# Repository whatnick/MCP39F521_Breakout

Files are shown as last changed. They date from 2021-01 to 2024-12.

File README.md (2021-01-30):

# MCP39F521 Breakout PCB

This is a basic breakout PCB for the [MCP39F521](https://www.microchip.com/wwwproducts/en/MCP39F521)
ASIC from Microchip. This ASIC has ADC's and an embedded PIC microcontroller to perform high-accuracy
energy measurements. The ASIC can appear in upto 4 i2c addresses based on jumper settings. The breakout
board is usable with this [Arduino Library](https://github.com/upbeatlabs/drwattson/tree/master/Arduino/UpbeatLabs_MCP39F521)

## PCB Design

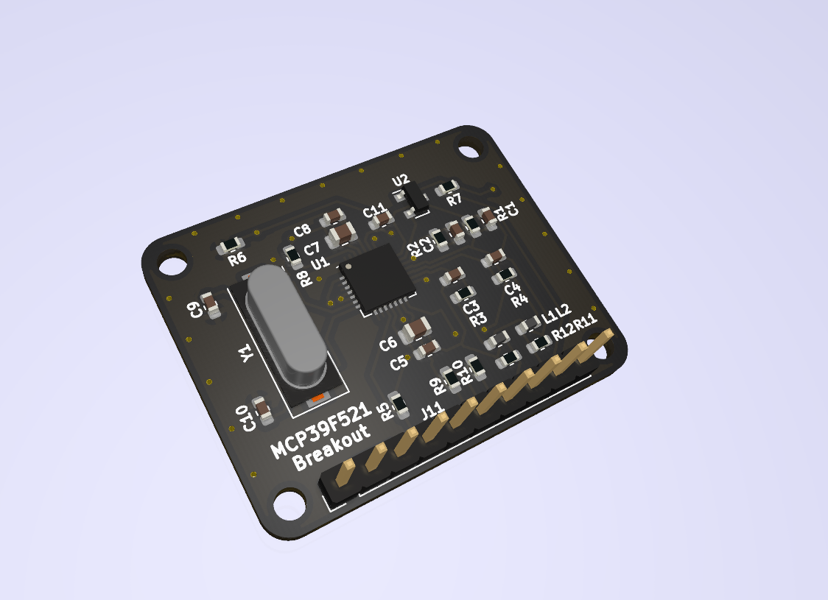
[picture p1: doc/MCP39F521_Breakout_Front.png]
PCB Front


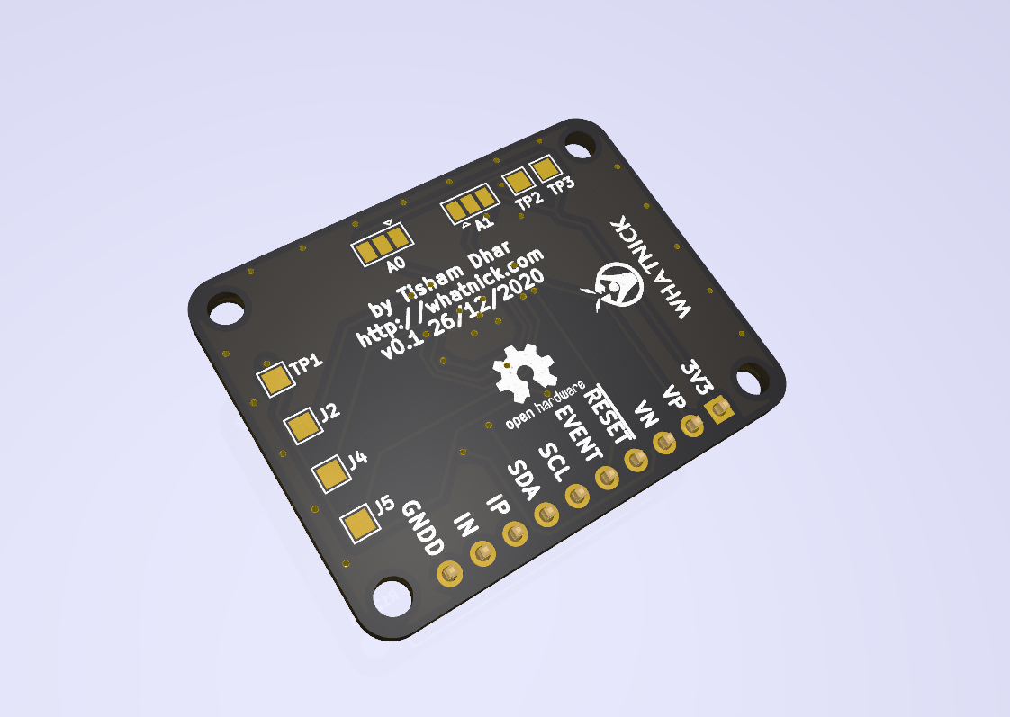
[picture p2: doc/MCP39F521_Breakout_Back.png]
PCB Back


## PCB Availabilty

- [Tindie]()
- [PCBWay]()
- [Aisler]()
- [OSHPark]()

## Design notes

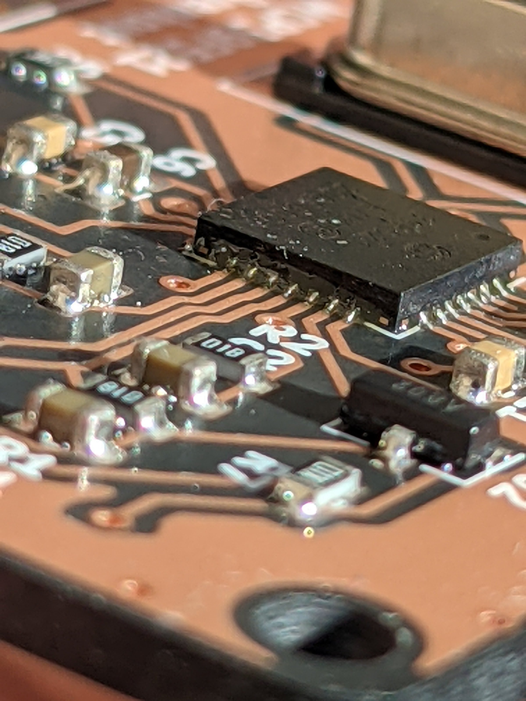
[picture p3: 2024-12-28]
doc/mcp39f521_zoom.jpg

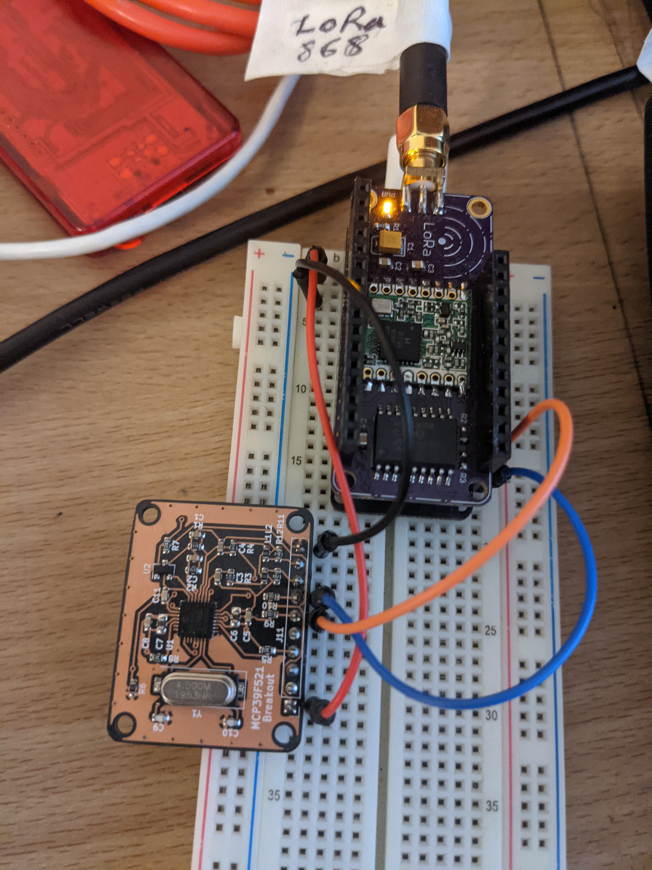
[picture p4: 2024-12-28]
doc/mcp39f521_i2c_connect.jpg

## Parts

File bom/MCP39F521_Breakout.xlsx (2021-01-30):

References | manf# | Value | Footprint | Quantity
C1, C2, C3, C4 | 0603YC333KAT2A | 33nF 50V | C_0603_1608Metric | 4
C5, C8, C11 | C0603C104K4PACTU | 0.1uF 25V | C_0603_1608Metric | 3
C9, C10 | C0603C220K4GACTU | 22pF | C_0603_1608Metric | 2
C6, C7 | CL21A225KAFNNNE | 2.2uF 25V | C_0805_2012Metric | 2
R7 | CR0603-FX-10R0ELF | 10R | R_0603_1608Metric | 1
R1, R2, R3, R4 | CR0603-FX-1501ELF | 1.5k | R_0603_1608Metric | 4
R9, R10 | CR0603-JW-222ELF | 2.2k | R_0603_1608Metric | 2
R5, R8 | CR0603-JW-472ELF | 4.7k | R_0603_1608Metric | 2
R6 | CR0603AJ/-000EAS | 0R | R_0603_1608Metric | 1
R11, R12 | CRL0603-FW-2R40ELF | 2.4R | R_0603_1608Metric | 2
L1, L2 | NFZ2MSD301SZ10L | FB 300ohm | L_0603_1608Metric | 2
U1 | MCP39F521-E/MQ | MCP39F521 | QFN-28-1EP_5x5mm_P0.5mm_EP3.35x3.35mm | 1
U2 | MCP9700T-E/TT | MCP9700AT-ETT | SOT-23 | 1
Y1 | LFXTAL003071Reel | Crystal | Crystal_SMD_HC49-SD | 1

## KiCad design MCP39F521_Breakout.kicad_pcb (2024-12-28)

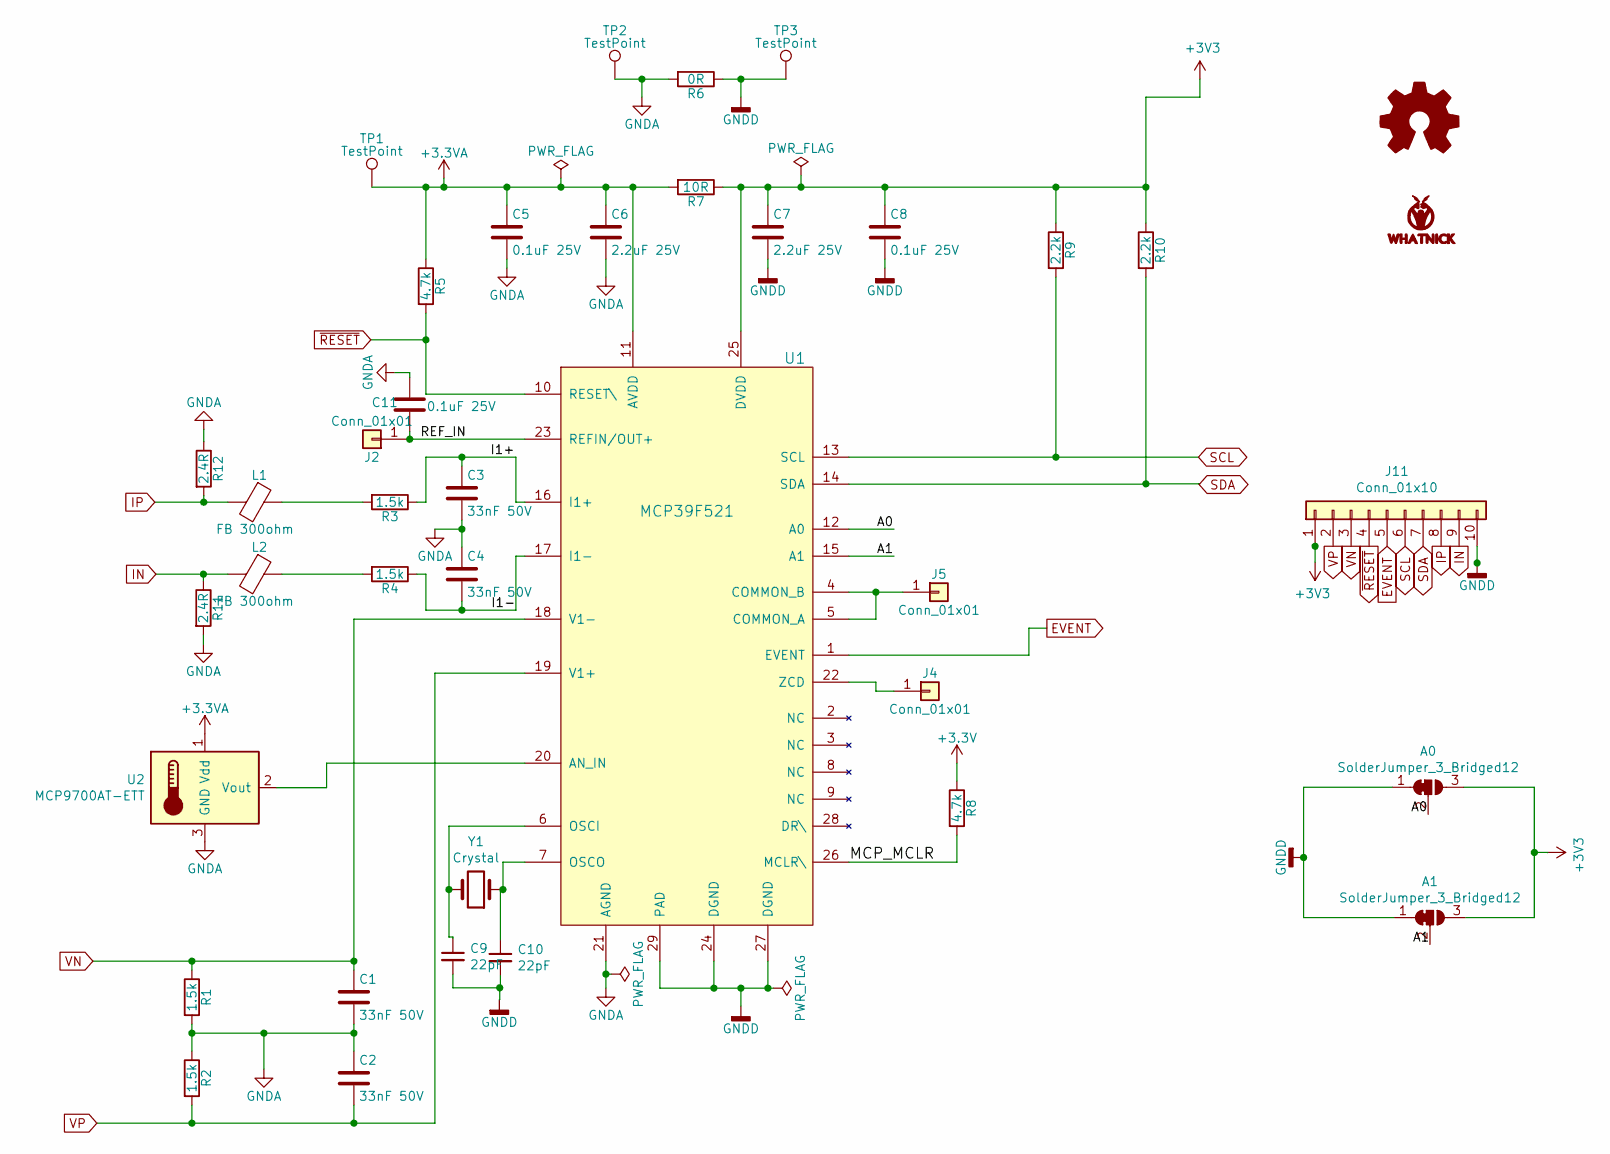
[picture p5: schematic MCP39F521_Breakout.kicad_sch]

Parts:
A0, A1: SolderJumper_3_Bridged12; SolderJumper-3_P1.3mm_Bridged12_Pad1.0x1.5mm
C1, C2, C3, C4: 33nF 50V; C_0603_1608Metric
C5, C8, C11: 0.1uF 25V; C_0603_1608Metric
C6, C7: 2.2uF 25V; C_0805_2012Metric
C9, C10: 22pF; C_0603_1608Metric
J2, J4, J5: Conn_01x01; TestPoint_Pad_1.5x1.5mm
J11: Conn_01x10; PinHeader_1x10_P2.54mm_Vertical
L1, L2: FB 300ohm; L_0603_1608Metric
LOGO1: Logo_Open_Hardware_Small; OSHW-Logo2_7.3x6mm_SilkScreen
LOGO2: LOGO; Whatnick_logo
R1, R2, R3, R4: 1.5k; R_0603_1608Metric
R5, R8: 4.7k; R_0603_1608Metric
R6: 0R; R_0603_1608Metric
R7: 10R; R_0603_1608Metric
R9, R10: 2.2k; R_0603_1608Metric
R11, R12: 2.4R; R_0603_1608Metric
TP1, TP2, TP3: TestPoint; TestPoint_Pad_1.5x1.5mm
U1: MCP39F521; QFN-28-1EP_5x5mm_P0.5mm_EP3.35x3.35mm
U2: MCP9700AT-ETT; SOT-23
Y1: Crystal; Crystal_SMD_HC49-SD

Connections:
+3.3VA: C5.1, C6.1, R5.1, R7.2, TP1.1, U1.11 (AVDD), U2.1 (Vdd)
/A0: A0.2 (C), U1.12 (A0)
/A1: A1.2 (C), U1.15 (A1)
/I1+: C3.1, R3.1, U1.16 (I1+)
/I1-: C4.2, R4.1, U1.17 (I1-)
/MCP_MCLR: R8.2, U1.26 (MCLR\)
/REF_IN: C11.2, J2.1, U1.23 (REFIN/OUT+)
EVENT: J11.5, U1.1 (EVENT)
GNDA: C1.2, C2.1, C3.2, C4.1, C5.2, C6.2, C11.1, R1.2, R2.1, R6.2, R11.2, R12.1, TP2.1, U1.21 (AGND), U2.3 (GND)
GNDD: A0.1 (A), A1.1 (A), C7.2, C8.2, C9.2, C10.2, J11.10, R6.1, TP3.1, U1.24 (DGND), U1.27 (DGND), U1.29 (PAD)
IN: J11.9, L2.2, R11.1
IP: J11.8, L1.2, R12.2
unnamed: C9.1, U1.6 (OSCI), Y1.2
unnamed: C10.1, U1.7 (OSCO), Y1.1
unnamed: J4.1, U1.22 (ZCD)
unnamed: J5.1, U1.4 (COMMON_B), U1.5 (COMMON_A)
unnamed: L1.1, R3.2
unnamed: L2.1, R4.2
unnamed: U1.20 (AN_IN), U2.2 (Vout)
SCL: J11.6, R9.2, U1.13 (SCL)
SDA: J11.7, R10.2, U1.14 (SDA)
VN: C1.1, J11.3, R1.1, U1.18 (V1-)
VP: C2.2, J11.2, R2.2, U1.19 (V1+)
~RESET: J11.4, R5.2, U1.10 (RESET\)

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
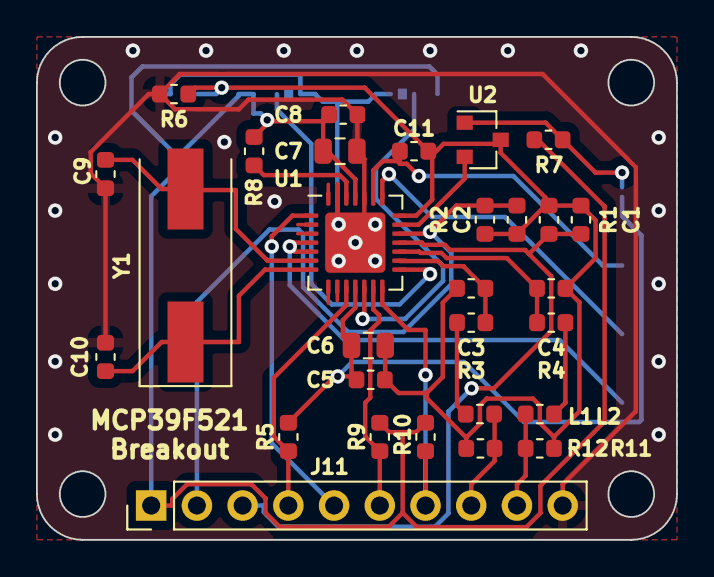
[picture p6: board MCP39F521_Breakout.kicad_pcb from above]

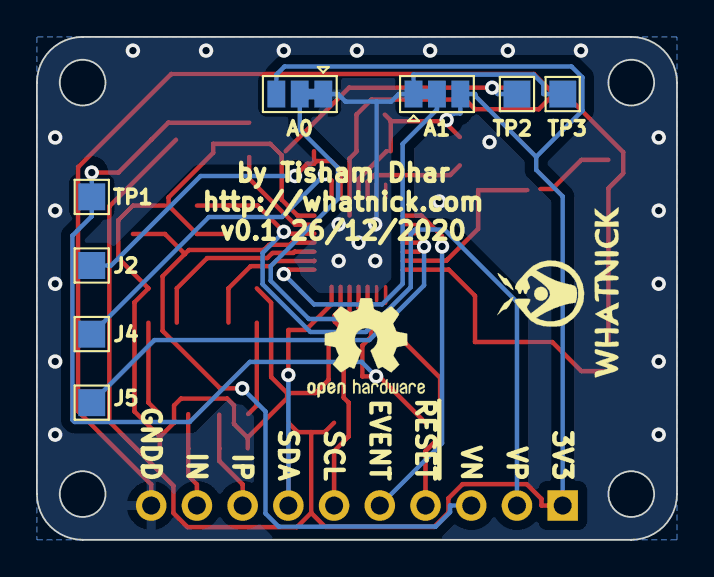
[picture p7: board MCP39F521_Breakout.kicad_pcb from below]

Board: 2 copper layers, 35.6 x 27.9 mm, 39 parts (10 on the bottom side), 25 nets.

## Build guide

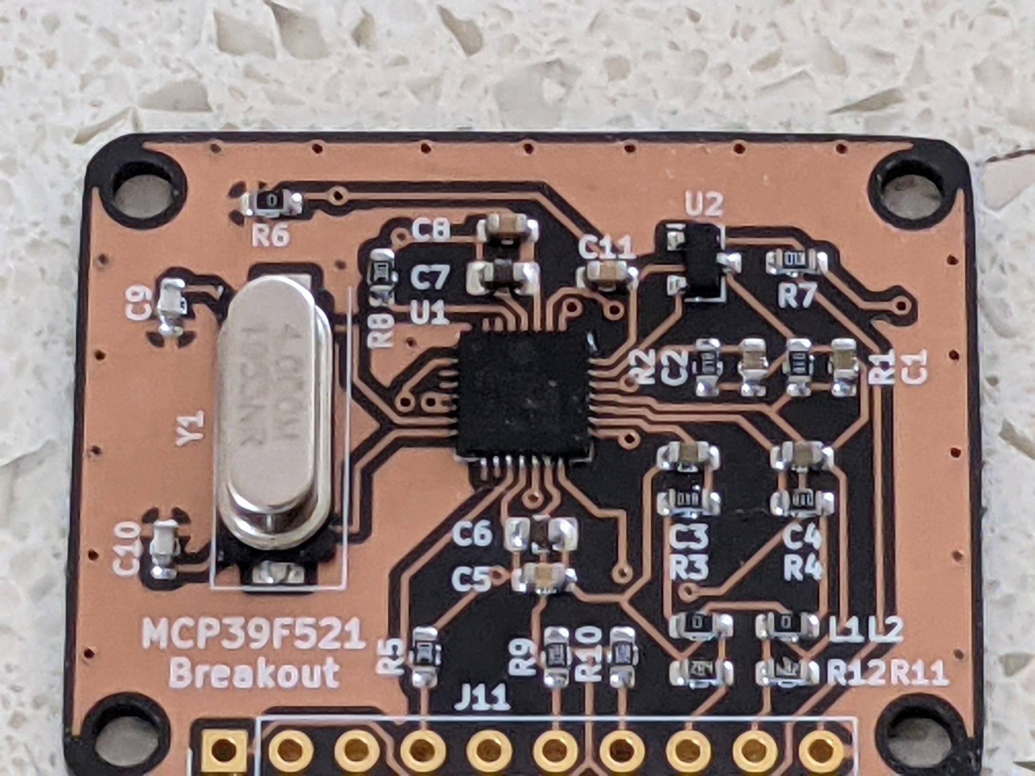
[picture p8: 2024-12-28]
doc/assembled_board.jpg

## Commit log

2020-12-25 Merry Christmas
    [MCP39F521_Breakout.kicad_pcb, MCP39F521_Breakout.kicad_sch]
2020-12-25 More wiring
    [MCP39F521_Breakout.kicad_pcb, MCP39F521_Breakout.kicad_sch]
2020-12-25 Add address jumpers
    [MCP39F521_Breakout.kicad_pcb, MCP39F521_Breakout.kicad_sch]
2020-12-25 Cleanup copy-pasted symbols and perform initial autoroute
    [MCP39F521_Breakout.kicad_pcb, MCP39F521_Breakout.kicad_sch]
2020-12-25 Clean-up initial route and setup net-classes
    [MCP39F521_Breakout.kicad_pcb]
2020-12-26 Ground planes and vias
    [MCP39F521_Breakout.kicad_pcb, MCP39F521_Breakout.kicad_sch]
2020-12-26 Clean up silk screen
    [MCP39F521_Breakout.kicad_pcb, MCP39F521_Breakout.kicad_sch]
2020-12-26 Create gerbers and swap to non-via footprint
    [MCP39F521_Breakout-B_Cu.gbl, MCP39F521_Breakout-B_Mask.gbs, MCP39F521_Breakout-B_Paste.gbp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]
2021-01-30 Updated BOM
    [MCP39F521_Breakout.kicad_pcb, MCP39F521_Breakout.kicad_sch, MCP39F521_Breakout.xlsx]
2021-08-14 Add footprint Positions
    [MCP39F521_Breakout-all-pos.csv]
2021-08-15 Regenerate Gerbers
    [MCP39F521_Breakout-B_Cu.gbl, MCP39F521_Breakout-B_Mask.gbs, MCP39F521_Breakout-B_Paste.gbp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]
2024-12-28 Update to v7 and add elecrow BOM
    [MCP39F521_Breakout.kicad_pcb, MCP39F521_Breakout.kicad_sch, MCP39F521_Breakout_Elecrow.xlsx]
